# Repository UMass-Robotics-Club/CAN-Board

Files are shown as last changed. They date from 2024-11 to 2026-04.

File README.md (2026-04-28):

# CAN Board
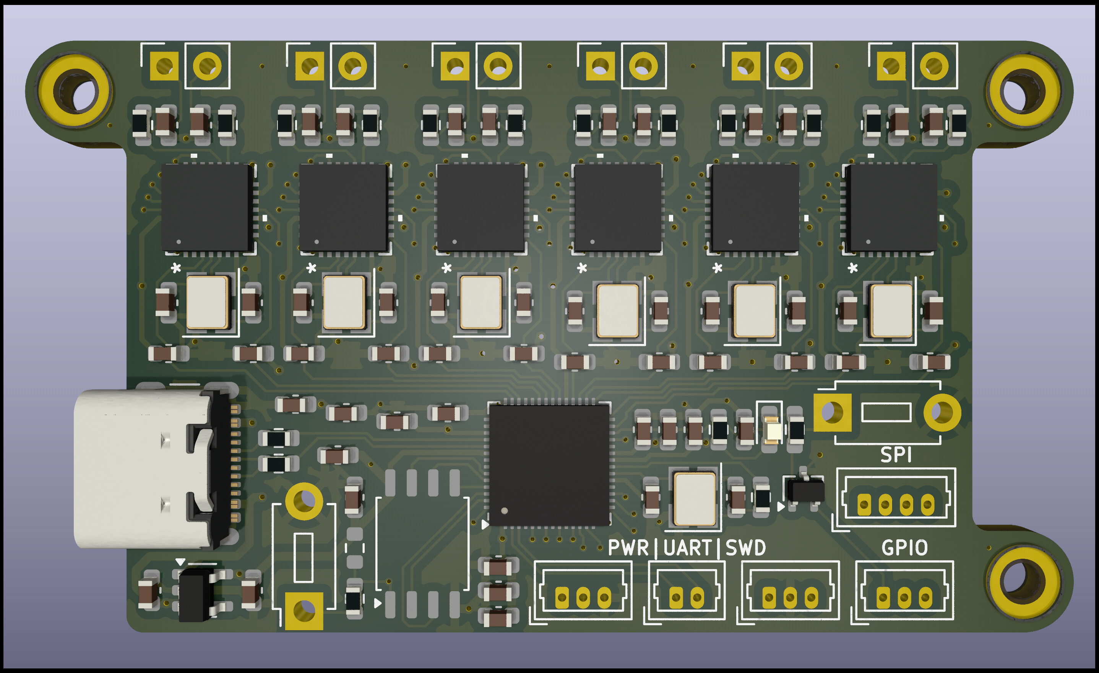
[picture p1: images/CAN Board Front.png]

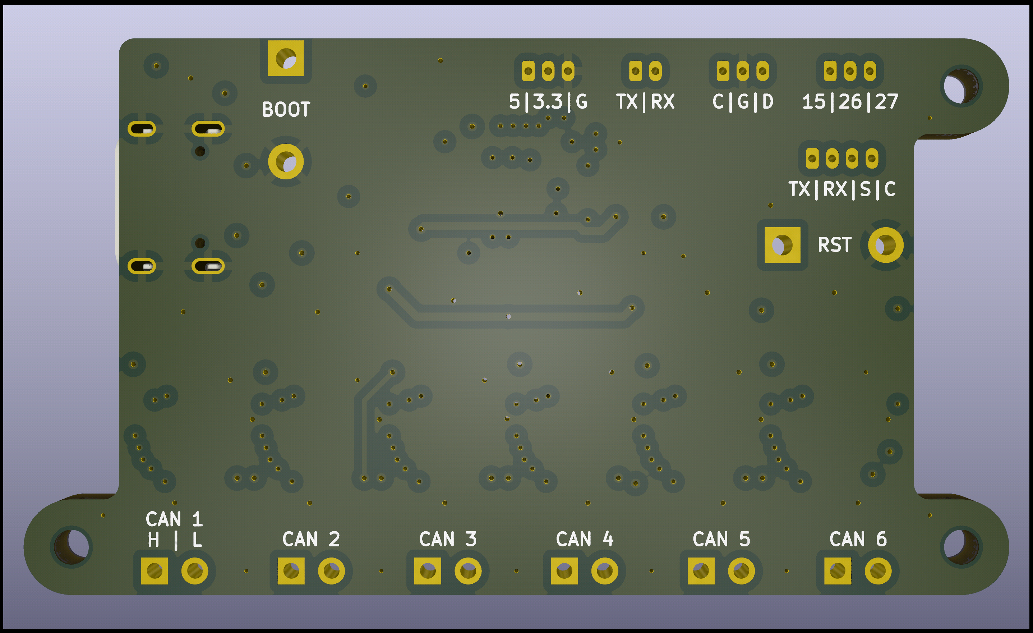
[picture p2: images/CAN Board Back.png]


Features:
* 6 CAN lines
* [RP2040](https://datasheets.raspberrypi.com/rp2040/rp2040-datasheet.pdf) microcontroller
* 16MB flash
* Many Interfaces
    * USB-C
    * UART
    * SPI
    * GPIO
* SWD debugging

This board has 6 independent CAN lines driven by 6 [MCP251863T-E/9PX](https://ww1.microchip.com/downloads/aemDocuments/documents/APID/ProductDocuments/DataSheets/MCP251863-External-CAN-FD-Controller-with-Integrated-Transceiver-DS200066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) CAN controllers. Each CAN controller is interfaced with the central microcontroller through an internal SPI bus along with 2 interrupt pins for general purpose and RX interrupts. There is also a STBY pin for the CAN transceiver that is connected to the XSTBY pin on the CAN controller.

## RP2040 Pinout
| GPIO | Function |
|---|---|
| 0 | UART TX | 
| 1 | UART RX |
| 2 | SPI0 SCK |
| 3 | SPI0 TX |
| 4 | SPI0 RX |
| 5 | SPI0 CS 1 |
| 6 | SPI0 CS 2 |
| 7 | SPI0 CS 3 |
| 8 | SPI0 CS 4 |
| 9 | SPI0 CS 5 |
| 10 | SPI0 CS 6 |
| 11 | SPI1 TX |
| 12 | SPI1 RX |
| 13 | SPI1 CS |
| 14 | SPI1 SCK |
| 15 | GPIO pin 1 |
| 16 | CAN6 RX INT |
| 17 | CAN6 INT |
| 18 | CAN5 RX INT |
| 19 | CAN5 INT |
| 20 | CAN4 RX INT |
| 21 | CAN4 INT |
| 22 | CAN3 RX INT |
| 23 | CAN3 INT |
| 24 | CAN2 RX INT |
| 25 | CAN2 INT |
| 26 | GPIO pin 2 |
| 27 | GPIO pin 3 |
| 28 | CAN1 RX INT |
| 29 | CAN1 INT |

Notes:
* `SPI0` is the internal SPI bus which connects to the CAN controllers with `SPI0 CS X` being the chip select for CAN controller X.
* `SPI1` is the SPI bus exposed over the SPI connector.
* `GPIO 15 (GPIO pin 1)` is attached to a mosfet and LED as an indicator and therefore should have pull down enabled if being used as an input.
* `GPIO 26 & 27 (GPIO pin 26 & 27)` can be used an analog inputs.
* `CANX INT` is a general purpose interrupt pin for CAN controller X that will trigger when any interrupt in the CAN controller is triggered. This pin is inverted (active LOW).
* `CANX RX INT` is configurable to trigger when CAN controller X's RX interrupt is triggered. As an interrupt, this pin is inverted (active LOW).

## Project Structure
* `CAD`: The kiCAD project (PCB/schematics)
    * `Components`: Imported components each in their own folder
* `code`: Firmware for the microcontroller in a pretty standard C project structure
    * `include`: Header files
    * `src`: C/C++ files
* `images`: All the images

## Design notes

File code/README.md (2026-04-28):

# Firmware for CAN Controller
This firmware is made for the RP2040 using the [picoSDK](https://github.com/raspberrypi/pico-sdk) along with the [CAN SDK](https://github.com/kentindell/canis-can-sdk) by [CANIS labs](https://canislabs.com/canpico/) to interface with the CAN controllers.

## Configuration
### Logging
By default, the firmware will output all log messages over USB. You can change what level of messages get logged by changing what macros are defined right above `#include "logging.h"` in [main.c](./src/main.c). You can also select what these messages are sent over (USB/external UART) by modifying the bottom of [CMakeLists.txt](./CMakeLists.txt).

### SPI and CAN
You can change both the SPI BAUD rate and the CAN bitrate at the top of [main.c](./src/main.c) under the user params section. The predefined CAN bit rates are in [canapi.h](./include/canapi.h) as follows:
```c
CAN_BITRATE_500K_75 = 0,    // 500kbit/sec 75% sample (default)    
CAN_BITRATE_250K_75,        // 250kbit/sec 75% sample point 
CAN_BITRATE_125K_75,        // 125kbit/sec 75% sample point
CAN_BITRATE_1M_75,          // 1Mbit/sec 75% sample point
CAN_BITRATE_500K_50,        // 500kbit/sec 50% sample (default)
CAN_BITRATE_250K_50,        // 250kbit/sec 50% sample point 
CAN_BITRATE_125K_50,        // 125kbit/sec 50% sample point
CAN_BITRATE_1M_50,          // 1Mbit/sec 50% sample point
CAN_BITRATE_2M_50,          // 2Mbit/sec 50% sample point NON STANDARD
CAN_BITRATE_4M_90,          // 4Mbit/sec 50% sample point NON STANDARD
CAN_BITRATE_2_5M_75 ,       // 2.5Mbit/sec 75% sample point NON STANDARD
CAN_BITRATE_2M_80,          // 2Mbit/sec 80% sample point NON STANDARD
CAN_BITRATE_500K_875,       // 500kbit/sec 87.5% sample
CAN_BITRATE_250K_875,       // 250kbit/sec 87.5% sample point (J1939, CANOpen) 
CAN_BITRATE_125K_875,       // 125kbit/sec 87.5% sample point
CAN_BITRATE_1M_875,         // 1Mbit/sec 85.5% sample point
```

## Build Instructions
1. Make a build folder inside `code`
```
mkdir build
cd build
```
2. Create the make files thorough cmake
```
cmake ..
```
3. Build the firmware using make
```
make
```
4. The output files should be inside the `build` folder

## Upload
```
sudo openocd -f interface/cmsis-dap.cfg -f target/rp2040.cfg -c "adapter speed 5000" -c "program can_board.elf verify reset exit"
```

## debug
```
gdb ./build/can_board.elf -ex 'set arch arm' -ex 'target extended-remote :3333'
```

# Better Communication Protocol

## Overall Architecture
The protocol is half duplex (even if the underlying transport is full duplex) and is based on a host-peripheral command architecture. The host will send a command along with any needed data and the peripheral will respond with a status code along with any data to return. The host MUST wait to the peripheral to respond before sending another command. If the peripheral does not receive a packet in time then it will send a timeout packet back. All data and commands will be wrapped in a general packet structure defined below. 

### General Command Structure
Host -> Peripheral:
- Frame start (1 byte): 0xAA
- Command (1 byte): The command that the controller should execute
- Data size (2 bytes): The size of the data included
- Data (n bytes): The data for the command (command specific)
- Frame end (1 byte): 0x55

Peripheral -> Host:
- Frame start (1 byte): 0xAA
- Response Code (1 byte): Status of the command
- Data size (2 bytes): The size of the data included
- Data (n bytes): The data for the command (command specific)
- Frame end (1 byte): 0x55

### Specific Command Structure
#### Send CAN Frame Command
Host -> Peripheral Data:
- Controller ID (1 byte): The ID of the controller to send the frame on
- Frame Options (1 byte): The options for the frame (e.g. extended ID, remote frame, etc.)
- Data Length Code (1 byte): The length of the data in bytes (0-8)
- Arbitration ID (2-4 bytes): The arbitration ID of the frame
- Frame Data (0-8 bytes): The data to be sent in the frame

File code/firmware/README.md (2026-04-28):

# Firmware — CAN Controller Board

## Overview

This folder contains the RP2040 firmware for the CAN controller board. It uses the Raspberry Pi Pico SDK and the MCP25xxFD CAN driver.

- **Microcontroller:** Raspberry Pi RP2040 (Pico)
- **CAN Controller:** MCP25xxFD (via SPI)
- **Number of CAN controllers:** 6 (configurable)
- **Communication:** USB CDC (default) or external SPI
- **Protocol:** Simple framed packet protocol (half-duplex, command-response)

## Contents

| Item | Purpose |
|---|---|
| [src/](src/) | Application sources: [main.c](src/main.c), [can.c](src/can.c) |
| [include/](include/) | Headers: [can.h](include/can.h), [pins.h](include/pins.h), [logging.h](include/logging.h) |
| [lib/mcp25xxfd/](lib/mcp25xxfd/) | Third-party MCP25xxFD CAN driver and RP2040 bindings |
| [CMakeLists.txt](CMakeLists.txt) | CMake build configuration for Pico SDK |

## Quick Start (Command-line Build)

From the `code` directory:

```bash
mkdir build
cd build
cmake ..
make
```

Build outputs: `can_board.elf`, `can_board.uf2` in `build/` directory.

## Building & Uploading with VS Code + Pico Extension

### Installation

1. **Install the official Raspberry Pi Pico extension**
   - Open VS Code Extensions (`Ctrl+Shift+X`)
   - Search for `Raspberry Pi Pico` (Publisher: Raspberry Pi)
   - Click **Install** on the official [Raspberry Pi Pico extension](https://marketplace.visualstudio.com/items?itemName=raspberry-pi.raspberry-pi-pico)
   - The extension will automatically download and configure the toolchain, SDK, and build tools (Ninja, CMake, arm-none-eabi-gcc)
   - **No manual toolchain installation required** — the extension handles it all

2. **Platform-specific notes**
   - **Windows / Raspberry Pi OS**: No additional prerequisites
   - **macOS**: Run `xcode-select --install` to install Xcode Command Line Tools
   - **Linux**: Ensure Python 3.10+, Git 2.28+, and Tar are installed and on your `PATH`

### Project Setup

1. **Open the folder in VS Code**
   - Open the project folder in VS Code (single folder workspace only)
   - The Pico extension will automatically detect the `CMakeLists.txt`

2. **Extension auto-configuration**
   - The extension automatically configures CMake on project load
   - You'll see the Pico extension status in the status bar at the bottom
   - If prompted, select **"Pico"** as the CMake kit

### Build Workflow

1. **Build** — Use any of the following:
   - Click the **Compile** button in the Pico extension status bar (bottom right)
   - Run `Ctrl+Shift+P` → Search `Raspberry Pi Pico: Compile Project`
   - Build output appears in the terminal; artifacts in `build/` folder (`can_board.elf`, `can_board.uf2`, etc.)

2. **Flash/Upload** — After building successfully:
   - **Option A (UF2 mass-storage, easiest):**
     - Put Pico into BOOTSEL mode: Hold BOOTSEL button while plugging USB into computer
     - Mounted drive will appear (RPI-RP2)
     - Copy `build/can_board.uf2` to the drive
     - Pico will auto-reboot and run the firmware
   
   - **Option B (Picotool, via extension):**
     - Connect Pico via USB with SWD/JTAG debugger (optional)
     - Run `Ctrl+Shift+P` → Search `Raspberry Pi Pico: Upload Project` (if available)
     - Extension uses `picotool` to flash via USB

3. **Debug** (optional, requires hardware debugger):
   - Connect CMSIS-DAP, ST-Link, or other SWD debugger to Pico
   - Run `Ctrl+Shift+P` → Search `Raspberry Pi Pico: Debug Project`
   - Extension automatically configures OpenOCD and GDB
   - Set breakpoints and step through code in the debugger

### Troubleshooting Extension Issues

- **CMake configuration fails**: Clear extension settings (`Ctrl+Shift+P` → `Preferences: Open Settings (UI)` → search `raspberry-pi-pico` → reset to defaults) then reload VS Code
- **Tools not downloading**: Check GitHub API rate limits; create a GitHub personal access token (with `public_repo` scope) and add to `raspberry-pi-pico.githubToken` in settings
- **Build fails**: Ensure `pico_sdk_import.cmake` is in the `firmware/` directory (it is, by default)

## Configuration

All configuration options are located in the files below. Edit them before building.

### Logging — [include/logging.h](include/logging.h)

Enable/disable log levels by defining or commenting out:

```c
#define ENABLE_TEST      // Development/testing (interferes with protocol in IRQ handler!)
#define ENABLE_DEBUG     // Debug-level messages
#define ENABLE_INFO      // Informational messages
#define ENABLE_WARNING   // Warning messages
#define ENABLE_ERROR     // Error messages
```

### Pins & Interfaces — [include/pins.h](include/pins.h)

| Parameter | Default | Purpose |
|---|---|---|
| `CAN_SPI` | `spi0` | Primary SPI bus for all 6 CAN controllers |
| `CAN_SPI_SCK` | 2 | SPI clock pin |
| `CAN_SPI_TX` | 3 | SPI TX (MOSI) pin |
| `CAN_SPI_RX` | 4 | SPI RX (MISO) pin |
| `can_spi_cs_pins[6]` | 5,6,7,8,9,10 | Chip select pins for 6 controllers |
| `can_int_pins[6]` | 29,25,23,21,19,17 | Interrupt pins for 6 controllers |
| `EXT_SPI` | `spi1` | External SPI (when `PKT_OVER_STDIO` is undefined) |
| `EXT_SPI_TX` | 11 | External SPI TX pin |
| `EXT_SPI_RX` | 12 | External SPI RX pin |
| `EXT_SPI_SCK` | 14 | External SPI clock pin |
| `EXT_SPI_CS` | 13 | External SPI chip select pin |
| `EXT_GPIO_15` | 15 | Activity LED GPIO (toggled during command processing) |

### User Parameters — [src/main.c](src/main.c)

Located in the "User params" section at the top of the file:

```c
#define EXT_SPI_BAUD 1000000        // External SPI baud rate (1 MHz default)
#define CAN_BITRATE CAN_BITRATE_1M_50   // CAN bitrate (see list below)
#define PKT_OVER_STDIO              // Use USB CDC for packets (comment to use EXT_SPI)
```

#### CAN Bitrate Profiles

All profiles are defined in [lib/mcp25xxfd/canapi.h](lib/mcp25xxfd/canapi.h). Use one as the value for `CAN_BITRATE`:

**Standard bitrates (75% sample point)**
- `CAN_BITRATE_500K_75` — 500 kbit/sec (default)
- `CAN_BITRATE_250K_75` — 250 kbit/sec
- `CAN_BITRATE_125K_75` — 125 kbit/sec
- `CAN_BITRATE_1M_75` — 1 Mbit/sec

**Standard bitrates (50% sample point)**
- `CAN_BITRATE_500K_50` — 500 kbit/sec
- `CAN_BITRATE_250K_50` — 250 kbit/sec
- `CAN_BITRATE_125K_50` — 125 kbit/sec
- `CAN_BITRATE_1M_50` — 1 Mbit/sec

**High-speed bitrates (50% sample point, non-standard)**
- `CAN_BITRATE_2M_50` — 2 Mbit/sec
- `CAN_BITRATE_4M_90` — 4 Mbit/sec (90% sample)

**Specialized bitrates (75%-87.5% sample points)**
- `CAN_BITRATE_2_5M_75` — 2.5 Mbit/sec (75% sample)
- `CAN_BITRATE_2M_80` — 2 Mbit/sec (80% sample)
- `CAN_BITRATE_500K_875` — 500 kbit/sec (87.5% sample)
- `CAN_BITRATE_250K_875` — 250 kbit/sec (87.5% sample, J1939/CANopen)
- `CAN_BITRATE_125K_875` — 125 kbit/sec (87.5% sample)
- `CAN_BITRATE_1M_875` — 1 Mbit/sec (85.5% sample)

**Custom bitrate**
- `CAN_BITRATE_CUSTOM` — Use a custom profile (manually set `brp`, `tseg1`, `tseg2`, `sjw` in `can_bitrate_t`)

### Controller Limits — [include/can.h](include/can.h)

```c
#define NUM_CAN_CONTROLLERS 6           // Number of MCP25xxFD controllers (fixed to 6)
#define CAN_SETUP_MAX_RETRIES 5         // Setup retry count (if transceiver slow to power)
#define CAN_TRANSMIT_MAX_TRYS 1         // Transmit retry count
```

## Code Structure

### [src/main.c](src/main.c)

**Entry point and packet loop.**

- **`main()`** — Initializes stdio, waits for USB CDC connection, initializes external SPI, calls `setup_can_controllers()`, enters main packet loop.
- **`loop()`** — Reads framed packets from transport (stdio or SPI), dispatches commands, sends responses.
- **Command handlers** — `handle_send_frame_cmd()`, `handle_recv_rx_events_cmd()`, `handle_recv_tx_events_cmd()`.

**Defines:**
- `host_command_t` — Command enum (SEND_FRAME, RECV_RX_EVENTS, RECV_TX_EVENTS, RECV_CAN_INFO)
- `command_resp_t` — Response codes (OK, BAD_PKT, CMD_UNKNOWN, CMD_MALFORMED, TIMEOUT, FAILED, NO_RESOURCES)
- `frame_options_t` — Frame flags (EXTENDED, REMOTE, USE_FIFO, USE_UREF)

### [src/can.c](src/can.c)

**CAN controller management and IRQ handling.**

- **`setup_can_controllers()`** — Initializes all 6 CAN controllers with given bitrate.
- **`send_can_frame()`** — Queue a CAN frame for transmission (with retries).
- **`get_can_rx_events()`** — Retrieve pending RX events for a controller.
- **`get_can_tx_events()`** — Retrieve pending TX events for a controller.
- **`can_irq_handler()`** — Shared IRQ handler (TIME_CRITICAL) that services all controllers.

### [include/can.h](include/can.h)

**Public constants and function declarations:**
- `NUM_CAN_CONTROLLERS`
- `can_controllers[]` — Array of `can_controller_t` instances
- Function prototypes for setup, send, and event retrieval

### [include/pins.h](include/pins.h)

**Board pin definitions:**
- SPI pins for CAN controllers
- External UART/SPI pins
- CS and interrupt pin arrays
- GPIO pins for activity indication

### [include/logging.h](include/logging.h)

**Logging macros:**
- `test()`, `debug()`, `info()`, `warning()`, `error()`
- Enable/disable via preprocessor defines
- Output via printf (configured in CMake to use stdio USB or UART)

### [lib/mcp25xxfd/](lib/mcp25xxfd/)

**Third-party CAN driver:**
- [lib/mcp25xxfd/canapi.h](lib/mcp25xxfd/canapi.h) — CAN API, bitrate profiles, data structures
- [lib/mcp25xxfd/mcp25xxfd.c](lib/mcp25xxfd/mcp25xxfd.c) — Main driver implementation
- [lib/mcp25xxfd/rp2/mcp25xxfd-rp2.h](lib/mcp25xxfd/rp2/mcp25xxfd-rp2.h) — RP2040-specific bindings

See [lib/mcp25xxfd/canapi.h](lib/mcp25xxfd/canapi.h) for `can_frame_t`, `can_rx_event_t`, `can_tx_event_t`, and other data structures.

## Host ↔ Peripheral Protocol

### Overview

The firmware implements a **half-duplex, framed packet protocol** over either USB CDC (STDIO) or external SPI. The host sends a command, the peripheral processes it, and responds with a status code and optional data.

### Packet Frame Format (both directions)

```
[0xAA] [Command/Response] [Data Size (2 bytes LE)] [Data (n bytes)] [0x55]
```

| Field | Size | Value |
|---|---|---|
| Frame start | 1 byte | `0xAA` |
| Command (host) / Response (peripheral) | 1 byte | See tables below |
| Data size | 2 bytes | Little-endian, 0–65535 |
| Data | n bytes | Command-specific payload |
| Frame end | 1 byte | `0x55` |

### Host → Peripheral Commands

From [src/main.c](src/main.c) `host_command_t`:

| Command | Byte | Payload | Purpose |
|---|---|---|---|
| `SEND_FRAME` | 0 | CAN frame + options | Send a CAN frame on specified controller |
| `RECV_RX_EVENTS` | 1 | Controller ID (1 byte) | Request pending RX events |
| `RECV_TX_EVENTS` | 2 | Controller ID (1 byte) | Request pending TX events |
| `RECV_CAN_INFO` | 3 | (reserved) | Reserved for future use |

### Peripheral → Host Responses

From [src/main.c](src/main.c) `command_resp_t`:

| Response | Value | Meaning |
|---|---|---|
| `CMD_RESPONSE_OK` | 0 | Success |
| `CMD_RESPONSE_BAD_PKT` | 1 | Frame start/end invalid |
| `CMD_RESPONSE_CMD_UNKNOWN` | 2 | Unknown command code |
| `CMD_RESPONSE_CMD_MALFORMED` | 3 | Payload size mismatch or invalid parameters |
| `CMD_RESPONSE_TIMEOUT` | 4 | Timeout waiting for input |
| `CMD_RESPONSE_FAILED` | 5 | Command execution failed (e.g., TX queue full) |
| `CMD_RESPONSE_NO_RESOURCES` | 6 | Memory allocation failed |

### SEND_FRAME Command Details

**Payload structure:**

```
[Controller ID] [Frame Options] [DLC] [Arbitration ID] [User Ref?] [Data]
```

| Field | Size | Notes |
|---|---|---|
| Controller ID | 1 byte | 0–5 (for 6 controllers) |
| Frame Options | 1 byte | Bit flags (see below) |
| DLC | 1 byte | Data length 0–8 |
| Arbitration ID | 2 or 4 bytes | 2 bytes if standard (11-bit), 4 bytes if extended (29-bit) |
| User Reference | 4 bytes | *Optional*, only if `FRAME_OPTION_USE_UREF` set |
| Frame Data | 0–8 bytes | Omitted if remote frame; length = DLC |

**Frame Options Flags:**

| Flag | Bit | Meaning |
|---|-----|---|
| `FRAME_OPTION_EXTENDED` | 0 (1<<0) | 29-bit arbitration ID (else 11-bit) |
| `FRAME_OPTION_REMOTE` | 1 (1<<1) | Remote frame (no data payload) |
| `FRAME_OPTION_USE_FIFO` | 2 (1<<2) | Use TX FIFO (else priority queue) |
| `FRAME_OPTION_USE_UREF` | 3 (1<<3) | Include 4-byte user reference |

**Example: Send 8-byte frame on controller 0, standard ID 0x123**

```
Frame start:     0xAA
Command:         0x00 (SEND_FRAME)
Data size:       0x0C, 0x00 (12 bytes)
Controller:      0x00
Options:         0x00 (standard, not remote, priority queue, no uref)
DLC:             0x08 (8 bytes)
Arbitration ID:  0x23, 0x01 (0x0123 LE)
Frame data:      0xAA, 0xBB, 0xCC, 0xDD, 0xEE, 0xFF, 0x00, 0x11
Frame end:       0x55
```

### RX/TX Events

- **`RECV_RX_EVENTS`** — Returns a packed buffer of receive events. Each event is `NUM_RX_EVENT_BYTES` bytes (19 bytes typically). Include the CAN frame, timestamp, and event type.
- **`RECV_TX_EVENTS`** — Returns a packed buffer of transmit events. Each event is `NUM_TX_EVENT_BYTES` bytes (9 bytes typically). Include user reference and timestamp.

See [lib/mcp25xxfd/canapi.h](lib/mcp25xxfd/canapi.h) for event structure definitions.

## Implementation Notes

### Key Points

- **Half-duplex protocol** — Host must wait for peripheral response before sending the next command.
- **Transport selection** — `PKT_OVER_STDIO` in [src/main.c](src/main.c) switches between USB CDC and external SPI.
- **Shared SPI bus** — All 6 CAN controllers share one SPI bus; IRQ handling adapted in [src/can.c](src/can.c).
- **Packet validation** — Strict size checking; mismatches return `CMD_RESPONSE_CMD_MALFORMED`.
- **Retry logic** — Controller setup retries up to `CAN_SETUP_MAX_RETRIES` times; useful if 3.3V present but 5V absent (affects transceiver power).

### Logging Output

- **Default:** USB CDC (`stdio_usb`)
- **Also available:** UART (`stdio_uart`)
- **Configure:** [CMakeLists.txt](CMakeLists.txt) — `pico_enable_stdio_usb()` and `pico_enable_stdio_uart()`

### Custom Bitrate

To use a custom bitrate, set `CAN_BITRATE` to `CAN_BITRATE_CUSTOM` and populate the `can_bitrate_t` struct in [src/main.c](src/main.c):

```c
can_bitrate_t bitrate = {
    .profile = CAN_BITRATE_CUSTOM,
    .brp = ...,       // Baud rate prescaler
    .tseg1 = ...,     // TSEG1 - 1
    .tseg2 = ...,     // TSEG2 - 1
    .sjw = ...        // SJW - 1
};
```

## Important Files Summary

| File | Purpose |
|---|---|
| [src/main.c](src/main.c) | Main loop, packet parsing, command handlers |
| [src/can.c](src/can.c) | CAN setup, IRQ handler, event retrieval |
| [include/pins.h](include/pins.h) | Pin definitions |
| [include/logging.h](include/logging.h) | Logging configuration |
| [include/can.h](include/can.h) | Public CAN constants |
| [lib/mcp25xxfd/canapi.h](lib/mcp25xxfd/canapi.h) | CAN API, bitrates, structures |
| [CMakeLists.txt](CMakeLists.txt) | Build configuration |

## Troubleshooting

**CAN controller fails to initialize**
- Check that 5V power is present on the transceiver (separate from 3.3V).
- Verify SPI pins and CS/IRQ pin assignments in [include/pins.h](include/pins.h).

**No USB CDC output**
- Ensure `pico_enable_stdio_usb()` is active in [CMakeLists.txt](CMakeLists.txt).
- Try toggling `PKT_OVER_STDIO` in [src/main.c](src/main.c) to use external SPI instead.

**Packets not received**
- Check transport (USB CDC vs. external SPI) is correctly selected and connected.
- Verify frame start (`0xAA`) and end (`0x55`) bytes are correct.
- Confirm controller ID is in range 0–5.

## Next Steps

- Add a Python host example that sends `SEND_FRAME` packets over USB CDC.
- Add `.vscode/launch.json` snippet for OpenOCD + GDB debugging (hardware debugger required).
- Add unit tests for packet parsing and frame layout validation.

---

Generated from firmware code analysis. Last updated: April 2026.

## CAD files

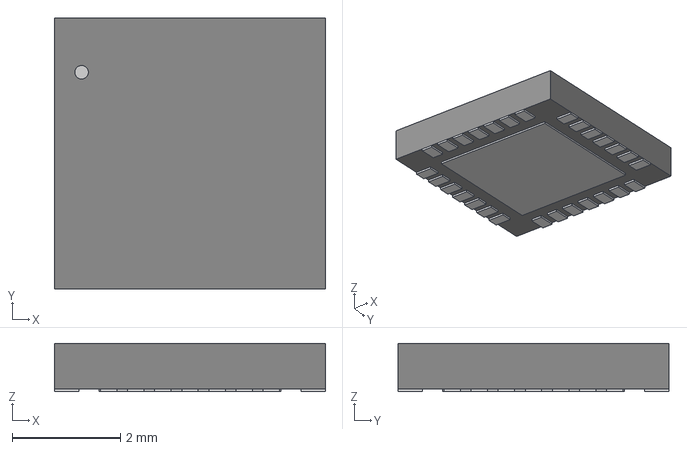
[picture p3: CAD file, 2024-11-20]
CAD/Components/MCP251863T_E_9PX/VQFN28_9PX_3p25X3p25EPAD_MCH.step
5.00 x 5.00 x 0.892 mm

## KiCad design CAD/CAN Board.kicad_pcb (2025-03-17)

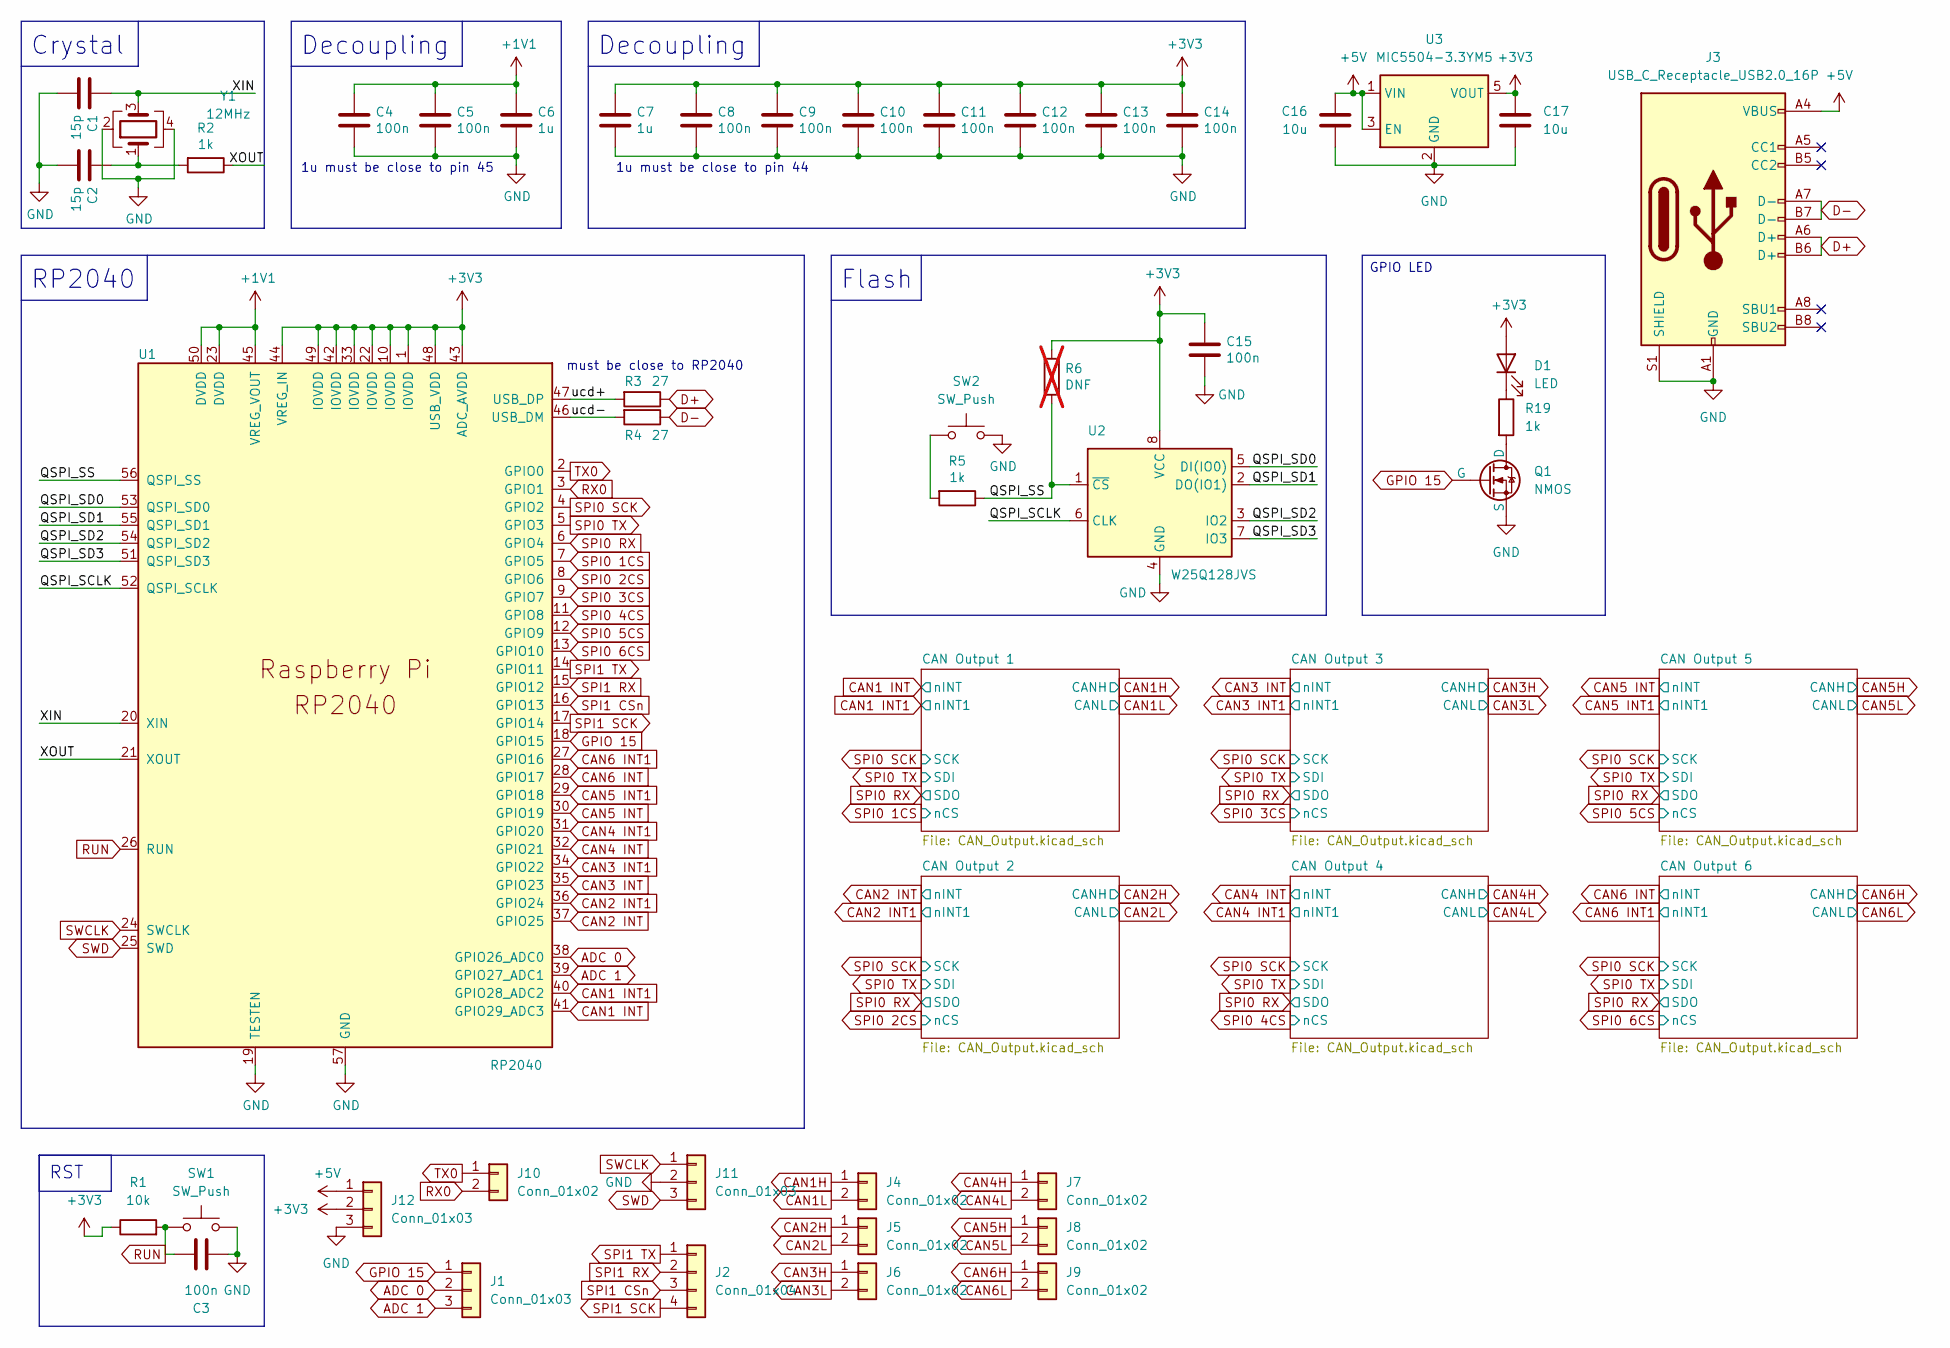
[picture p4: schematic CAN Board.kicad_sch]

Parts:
C1, C2: 15p; C_0603_1608Metric
C3, C4, C5, C8, C9, C10, C11, C12, C13, C14, C15: 100n; C_0603_1608Metric
C6, C7: 1u; C_0603_1608Metric
C16, C17: 10u; C_0603_1608Metric
D1: LED; LED_0603_1608Metric_Pad1.05x0.95mm_HandSolder
J1, J11, J12: Conn_01x03; Molex_PicoBlade_53047-0310_1x03_P1.25mm_Vertical
J2: Conn_01x04; Molex_PicoBlade_53047-0410_1x04_P1.25mm_Vertical
J3: USB_C_Receptacle_USB2.0_16P; USB_C_Receptacle_GCT_USB4105-xx-A_16P_TopMnt_Horizontal
J4, J5, J6, J7, J8, J9: Conn_01x02; PinSocket_1x02_P2.54mm_Vertical
J10: Conn_01x02; Molex_PicoBlade_53047-0210_1x02_P1.25mm_Vertical
Q1: NMOS; SOT-323_SC-70
R1: 10k; R_0603_1608Metric
R2, R5, R19: 1k; R_0603_1608Metric
R3, R4: 27; R_0603_1608Metric
R6: DNF; R_0603_1608Metric; not fitted
SW1, SW2: SW_Push; SW_PUSH_1P1T_6x3.5mm_H5.0_APEM_MJTP1250
U1: RP2040; QFN-56-1EP_7x7mm_P0.4mm_EP3.2x3.2mm
U2: W25Q128JVS; SOIC-8_5.23x5.23mm_P1.27mm
U3: MIC5504-3.3YM5; SOT-23-5
Y1: 12MHz; Crystal_SMD_3225-4Pin_3.2x2.5mm

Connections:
+1V1: C4.1, C5.1, C6.1, U1.23 (DVDD), U1.45 (VREG_VOUT), U1.50 (DVDD)
+3V3: C7.1, C8.1, C9.1, C10.1, C11.1, C12.1, C13.1, C14.1, C15.1, C17.1, D1.2 (A), J12.2, R1.1, R6.1, U1.1 (IOVDD), U1.10 (IOVDD), U1.22 (IOVDD), U1.33 (IOVDD), U1.42 (IOVDD), U1.43 (ADC_AVDD), U1.44 (VREG_IN), U1.48 (USB_VDD), U1.49 (IOVDD), U2.8 (VCC), U3.5 (VOUT); also elsewhere on the board
+5V: C16.1, J3.A4 (VBUS), J3.A9 (VBUS), J3.B4 (VBUS), J3.B9 (VBUS), J12.1, U3.1 (VIN), U3.3 (EN); also elsewhere on the board
/QSPI_SCLK: U1.52 (QSPI_SCLK), U2.6 (CLK)
/QSPI_SD0: U1.53 (QSPI_SD0), U2.5 (DI(IO0))
/QSPI_SD1: U1.55 (QSPI_SD1), U2.2 (DO(IO1))
/QSPI_SD2: U1.54 (QSPI_SD2), U2.3 (IO2)
/QSPI_SD3: U1.51 (QSPI_SD3), U2.7 (IO3)
/QSPI_SS: R5.1, R6.2, U1.56 (QSPI_SS), U2.1 (~CS)
/XIN: C1.1, U1.20 (XIN), Y1.3
/XOUT: R2.1, U1.21 (XOUT)
/ucd+: R3.2, U1.47 (USB_DP)
/ucd-: R4.2, U1.46 (USB_DM)
ADC 0: J1.2, U1.38 (GPIO26_ADC0)
ADC 1: J1.3, U1.39 (GPIO27_ADC1)
CAN1 INT: U1.41 (GPIO29_ADC3); also elsewhere on the board
CAN1 INT1: U1.40 (GPIO28_ADC2); also elsewhere on the board
CAN1H: J4.1; also elsewhere on the board
CAN1L: J4.2; also elsewhere on the board
CAN2 INT: U1.37 (GPIO25); also elsewhere on the board
CAN2 INT1: U1.36 (GPIO24); also elsewhere on the board
CAN2H: J5.1; also elsewhere on the board
CAN2L: J5.2; also elsewhere on the board
CAN3 INT: U1.35 (GPIO23); also elsewhere on the board
CAN3 INT1: U1.34 (GPIO22); also elsewhere on the board
CAN3H: J6.1; also elsewhere on the board
CAN3L: J6.2; also elsewhere on the board
CAN4 INT: U1.32 (GPIO21); also elsewhere on the board
CAN4 INT1: U1.31 (GPIO20); also elsewhere on the board
CAN4H: J7.1; also elsewhere on the board
CAN4L: J7.2; also elsewhere on the board
CAN5 INT: U1.30 (GPIO19); also elsewhere on the board
CAN5 INT1: U1.29 (GPIO18); also elsewhere on the board
CAN5H: J8.1; also elsewhere on the board
CAN5L: J8.2; also elsewhere on the board
CAN6 INT: U1.28 (GPIO17); also elsewhere on the board
CAN6 INT1: U1.27 (GPIO16); also elsewhere on the board
CAN6H: J9.1; also elsewhere on the board
CAN6L: J9.2; also elsewhere on the board
D+: J3.A6 (D+), J3.B6 (D+), R3.1
D-: J3.A7 (D-), J3.B7 (D-), R4.1
GND: C1.2, C2.2, C3.2, C4.2, C5.2, C6.2, C7.2, C8.2, C9.2, C10.2, C11.2, C12.2, C13.2, C14.2, C15.2, C16.2, C17.2, J3.A1 (GND), J3.A12 (GND), J3.B1 (GND), J3.B12 (GND), J3.S1 (SHIELD), J11.2, J12.3, Q1.3 (S), SW1.2, SW2.2, U1.19 (TESTEN), U1.57 (GND), U2.4 (GND), U3.2 (GND), Y1.2, Y1.4; also elsewhere on the board
GPIO 15: J1.1, Q1.2 (G), U1.18 (GPIO15)
unnamed: C2.1, R2.2, Y1.1
unnamed: D1.1 (K), R19.1
unnamed: Q1.1 (D), R19.2
unnamed: R5.2, SW2.1
RUN: C3.1, R1.2, SW1.1, U1.26 (RUN)
RX0: J10.2, U1.3 (GPIO1)
SPI0 1CS: U1.7 (GPIO5); also elsewhere on the board
SPI0 2CS: U1.8 (GPIO6); also elsewhere on the board
SPI0 3CS: U1.9 (GPIO7); also elsewhere on the board
SPI0 4CS: U1.11 (GPIO8); also elsewhere on the board
SPI0 5CS: U1.12 (GPIO9); also elsewhere on the board
SPI0 6CS: U1.13 (GPIO10); also elsewhere on the board
SPI0 RX: U1.6 (GPIO4); also elsewhere on the board
SPI0 SCK: U1.4 (GPIO2); also elsewhere on the board
SPI0 TX: U1.5 (GPIO3); also elsewhere on the board
SPI1 CSn: J2.3, U1.16 (GPIO13)
SPI1 RX: J2.2, U1.15 (GPIO12)
SPI1 SCK: J2.4, U1.17 (GPIO14)
SPI1 TX: J2.1, U1.14 (GPIO11)
SWCLK: J11.1, U1.24 (SWCLK)
SWD: J11.3, U1.25 (SWD)
TX0: J10.1, U1.2 (GPIO0)

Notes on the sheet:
Crystal
RP2040
Decoupling
Flash
must be close to RP2040
1u must be close to pin 45
1u must be close to pin 44
GPIO LED
RST

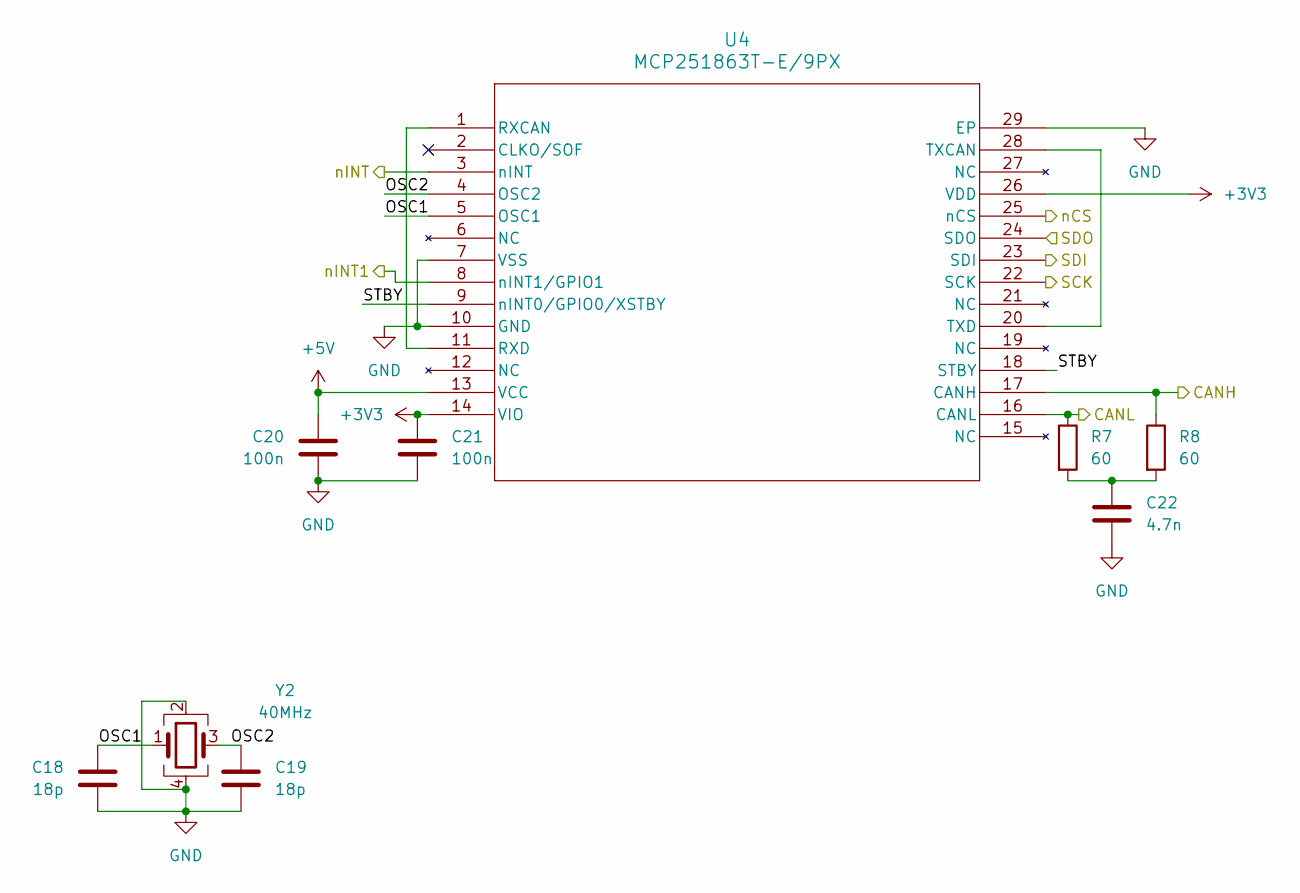
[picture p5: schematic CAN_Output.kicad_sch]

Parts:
C18, C19: 18p; C_0603_1608Metric
C20, C21: 100n; C_0603_1608Metric
C22: 4.7n; C_0603_1608Metric
R7, R8: 60; R_0603_1608Metric
U4: MCP251863T-E/9PX; VQFN28_9PX_3p25X3p25EPAD_MCH
Y2: 40MHz; Crystal_SMD_3225-4Pin_3.2x2.5mm

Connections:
+3V3: C21.1, U4.14 (VIO), U4.26 (VDD); also elsewhere on the board
+5V: C20.1, U4.13 (VCC); also elsewhere on the board
/CAN Output 1/OSC1: C18.1, U4.5 (OSC1), Y2.1
/CAN Output 1/OSC2: C19.1, U4.4 (OSC2), Y2.3
/CAN Output 1/STBY: U4.9 (nINT0/GPIO0/XSTBY), U4.18 (STBY)
CAN1 INT: U4.3 (nINT); also elsewhere on the board
CAN1 INT1: U4.8 (nINT1/GPIO1); also elsewhere on the board
CAN1H: R8.1, U4.17 (CANH); also elsewhere on the board
CAN1L: R7.1, U4.16 (CANL); also elsewhere on the board
GND: C18.2, C19.2, C20.2, C21.2, C22.2, U4.7 (VSS), U4.10 (GND), U4.29 (EP), Y2.2, Y2.4; also elsewhere on the board
unnamed: C22.1, R7.2, R8.2
unnamed: U4.1 (RXCAN), U4.11 (RXD)
unnamed: U4.20 (TXD), U4.28 (TXCAN)
SPI0 1CS: U4.25 (nCS); also elsewhere on the board
SPI0 RX: U4.24 (SDO); also elsewhere on the board
SPI0 SCK: U4.22 (SCK); also elsewhere on the board
SPI0 TX: U4.23 (SDI); also elsewhere on the board

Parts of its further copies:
C25, C26, C32, C33, C39, C40, C46, C47, C53, C54: 18p; C_0603_1608Metric
C27, C28, C34, C35, C41, C42, C48, C49, C55, C56: 100n; C_0603_1608Metric
C29, C36, C43, C50, C57: 4.7n; C_0603_1608Metric
R9, R10, R11, R12, R13, R14, R15, R16, R17, R18: 60; R_0603_1608Metric
U5, U6, U7, U8, U9: MCP251863T-E/9PX; VQFN28_9PX_3p25X3p25EPAD_MCH
Y3, Y4, Y5, Y6, Y7: 40MHz; Crystal_SMD_3225-4Pin_3.2x2.5mm

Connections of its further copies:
+3V3: C28.1, C35.1, C42.1, C49.1, C56.1, U5.14 (VIO), U5.26 (VDD), U6.14 (VIO), U6.26 (VDD), U7.14 (VIO), U7.26 (VDD), U8.14 (VIO), U8.26 (VDD), U9.14 (VIO), U9.26 (VDD); also elsewhere on the board
+5V: C27.1, C34.1, C41.1, C48.1, C55.1, U5.13 (VCC), U6.13 (VCC), U7.13 (VCC), U8.13 (VCC), U9.13 (VCC); also elsewhere on the board
/CAN Output 2/OSC1: C25.1, U5.5 (OSC1), Y3.1
/CAN Output 2/OSC2: C26.1, U5.4 (OSC2), Y3.3
/CAN Output 2/STBY: U5.9 (nINT0/GPIO0/XSTBY), U5.18 (STBY)
/CAN Output 3/OSC1: C32.1, U6.5 (OSC1), Y4.1
/CAN Output 3/OSC2: C33.1, U6.4 (OSC2), Y4.3
/CAN Output 3/STBY: U6.9 (nINT0/GPIO0/XSTBY), U6.18 (STBY)
/CAN Output 4/OSC1: C39.1, U7.5 (OSC1), Y5.1
/CAN Output 4/OSC2: C40.1, U7.4 (OSC2), Y5.3
/CAN Output 4/STBY: U7.9 (nINT0/GPIO0/XSTBY), U7.18 (STBY)
/CAN Output 5/OSC1: C46.1, U8.5 (OSC1), Y6.1
/CAN Output 5/OSC2: C47.1, U8.4 (OSC2), Y6.3
/CAN Output 5/STBY: U8.9 (nINT0/GPIO0/XSTBY), U8.18 (STBY)
/CAN Output 6/OSC1: C53.1, U9.5 (OSC1), Y7.1
/CAN Output 6/OSC2: C54.1, U9.4 (OSC2), Y7.3
/CAN Output 6/STBY: U9.9 (nINT0/GPIO0/XSTBY), U9.18 (STBY)
CAN2 INT: U5.3 (nINT); also elsewhere on the board
CAN2 INT1: U5.8 (nINT1/GPIO1); also elsewhere on the board
CAN2H: R10.1, U5.17 (CANH); also elsewhere on the board
CAN2L: R9.1, U5.16 (CANL); also elsewhere on the board
CAN3 INT: U6.3 (nINT); also elsewhere on the board
CAN3 INT1: U6.8 (nINT1/GPIO1); also elsewhere on the board
CAN3H: R12.1, U6.17 (CANH); also elsewhere on the board
CAN3L: R11.1, U6.16 (CANL); also elsewhere on the board
CAN4 INT: U7.3 (nINT); also elsewhere on the board
CAN4 INT1: U7.8 (nINT1/GPIO1); also elsewhere on the board
CAN4H: R14.1, U7.17 (CANH); also elsewhere on the board
CAN4L: R13.1, U7.16 (CANL); also elsewhere on the board
CAN5 INT: U8.3 (nINT); also elsewhere on the board
CAN5 INT1: U8.8 (nINT1/GPIO1); also elsewhere on the board
CAN5H: R16.1, U8.17 (CANH); also elsewhere on the board
CAN5L: R15.1, U8.16 (CANL); also elsewhere on the board
CAN6 INT: U9.3 (nINT); also elsewhere on the board
CAN6 INT1: U9.8 (nINT1/GPIO1); also elsewhere on the board
CAN6H: R18.1, U9.17 (CANH); also elsewhere on the board
CAN6L: R17.1, U9.16 (CANL); also elsewhere on the board
GND: C25.2, C26.2, C27.2, C28.2, C29.2, C32.2, C33.2, C34.2, C35.2, C36.2, C39.2, C40.2, C41.2, C42.2, C43.2, C46.2, C47.2, C48.2, C49.2, C50.2, C53.2, C54.2, C55.2, C56.2, C57.2, U5.7 (VSS), U5.10 (GND), U5.29 (EP), U6.7 (VSS), U6.10 (GND), U6.29 (EP), U7.7 (VSS), U7.10 (GND), U7.29 (EP), U8.7 (VSS), U8.10 (GND), U8.29 (EP), U9.7 (VSS), U9.10 (GND), U9.29 (EP), Y3.2, Y3.4, Y4.2, Y4.4, Y5.2, Y5.4, Y6.2, Y6.4, Y7.2, Y7.4; also elsewhere on the board
unnamed: C29.1, R9.2, R10.2
unnamed: C36.1, R11.2, R12.2
unnamed: C43.1, R13.2, R14.2
unnamed: C50.1, R15.2, R16.2
unnamed: C57.1, R17.2, R18.2
unnamed: U5.1 (RXCAN), U5.11 (RXD)
unnamed: U5.20 (TXD), U5.28 (TXCAN)
unnamed: U6.1 (RXCAN), U6.11 (RXD)
unnamed: U6.20 (TXD), U6.28 (TXCAN)
unnamed: U7.1 (RXCAN), U7.11 (RXD)
unnamed: U7.20 (TXD), U7.28 (TXCAN)
unnamed: U8.1 (RXCAN), U8.11 (RXD)
unnamed: U8.20 (TXD), U8.28 (TXCAN)
unnamed: U9.1 (RXCAN), U9.11 (RXD)
unnamed: U9.20 (TXD), U9.28 (TXCAN)
SPI0 2CS: U5.25 (nCS); also elsewhere on the board
SPI0 3CS: U6.25 (nCS); also elsewhere on the board
SPI0 4CS: U7.25 (nCS); also elsewhere on the board
SPI0 5CS: U8.25 (nCS); also elsewhere on the board
SPI0 6CS: U9.25 (nCS); also elsewhere on the board
SPI0 RX: U5.24 (SDO), U6.24 (SDO), U7.24 (SDO), U8.24 (SDO), U9.24 (SDO); also elsewhere on the board
SPI0 SCK: U5.22 (SCK), U6.22 (SCK), U7.22 (SCK), U8.22 (SCK), U9.22 (SCK); also elsewhere on the board
SPI0 TX: U5.23 (SDI), U6.23 (SDI), U7.23 (SDI), U8.23 (SDI), U9.23 (SDI); also elsewhere on the board

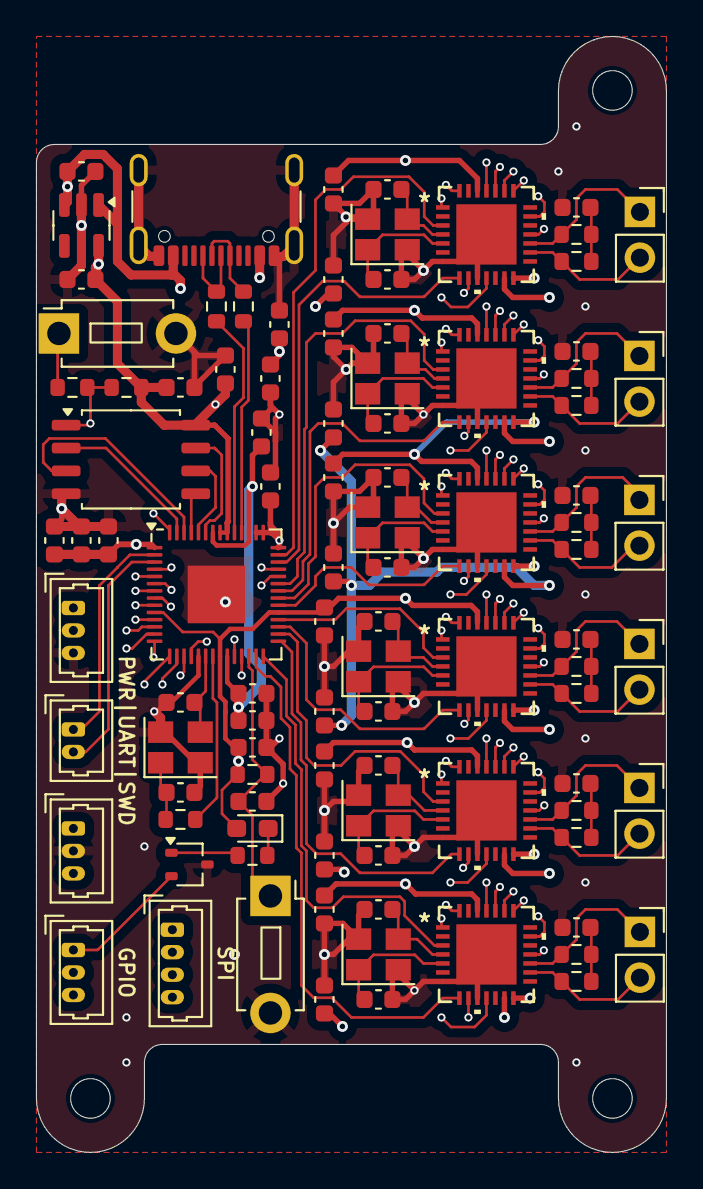
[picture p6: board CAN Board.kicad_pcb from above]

Board: 4 copper layers, 35.0 x 62.0 mm, 98 parts (0 on the bottom side), 101 nets.

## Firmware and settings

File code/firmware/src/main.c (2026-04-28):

#include "pico/stdlib.h"
#include "malloc.h"

#include "tusb.h" // Required for tud_cdc_connected()
#include "hardware/spi.h"

#include "canapi.h"

#include "pins.h"
#include "logging.h"
#include "can.h"

///////////////////////////////////////
// User params
///////////////////////////////////////

#define EXT_SPI_BAUD 1000000
#define CAN_BITRATE CAN_BITRATE_1M_50

// get protocol data over stdio else it will use SPI
#define PKT_OVER_STDIO

#ifdef PKT_OVER_STDIO
#define read_bytes(buff, len) fread(buff, len, 1, stdin)
#define write_bytes(buff, len)    \
    fwrite(buff, len, 1, stdout); \
    fflush(stdout)
#else
#define read_bytes(buff, len) spi_read_blocking(EXT_SPI, 0, buff, len)
#define write_bytes(buff, len) spi_write_blocking(EXT_SPI, buff, len)
#endif

#define wrap_led_on(statements) \
    gpio_put(EXT_GPIO_15, 0);   \
    statements                  \
        gpio_put(EXT_GPIO_15, 1);

/**
 * Initializes the external spi
 */
void init_ext_spi()
{
    debug("EXT SPI setup: Starting setup...\n");

    uint baud = spi_init(EXT_SPI, EXT_SPI_BAUD);
    spi_set_slave(EXT_SPI, true);

    gpio_set_function(EXT_SPI_SCK, GPIO_FUNC_SPI);
    gpio_set_function(EXT_SPI_TX, GPIO_FUNC_SPI);
    gpio_set_function(EXT_SPI_RX, GPIO_FUNC_SPI);
    gpio_set_function(EXT_SPI_CS, GPIO_FUNC_SPI);

    debug("EXT SPI setup: Done setting up at baud %u!\n", baud);
}

typedef enum : uint8_t
{
    SEND_FRAME,
    RECV_RX_EVENTS,
    RECV_TX_EVENTS,
    RECV_CAN_INFO
} host_command_t;

typedef enum : uint8_t
{
    CMD_RESPONSE_OK,
    CMD_RESPONSE_BAD_PKT,
    CMD_RESPONSE_CMD_UNKNOWN,
    CMD_RESPONSE_CMD_MALFORMED,
    CMD_RESPONSE_TIMEOUT,
    CMD_RESPONSE_FAILED,
    CMD_RESPONSE_NO_RESOURCES
} command_resp_t;

typedef enum : uint8_t
{
    FRAME_OPTION_EXTENDED = (1 << 0), // Use CAN extended 29 bit arbitration
    FRAME_OPTION_REMOTE = (1 << 1),   // This is a CAN remote frame
    FRAME_OPTION_USE_FIFO = (1 << 2), // Use TX FIFO instead of directly going into TX priority queue
    FRAME_OPTION_USE_UREF = (1 << 3), // Add a user reference to the frame (else it will default to 0)
} frame_options_t;

typedef struct
{
    uint8_t controller;
    frame_options_t options;
    uint8_t dlc;
} send_frame_cmd_data_t;

void send_response_pkt(command_resp_t resp_code, void *data, uint16_t data_size)
{
    uint8_t tmp = 0xAA;
    write_bytes(&tmp, 1);
    write_bytes(&resp_code, sizeof(resp_code));
    write_bytes(&data_size, 2);
    if (data_size)
        write_bytes(data, data_size);
    tmp = 0x55;
    write_bytes(&tmp, 1);
}

void handle_send_frame_cmd(uint8_t *data, uint16_t data_size)
{
    // Extract frame header data
    if (data_size < sizeof(send_frame_cmd_data_t))
    {
        error("Send frame: Not enough data supplied to extract header (expected %hhd, got %hhd)\n", sizeof(send_frame_cmd_data_t), data_size);
        send_response_pkt(CMD_RESPONSE_CMD_MALFORMED, NULL, 0);
        return;
    }
    send_frame_cmd_data_t *frame_cmd_data = (send_frame_cmd_data_t *)data;

    bool extended = (frame_cmd_data->options & FRAME_OPTION_EXTENDED);
    bool remote = (frame_cmd_data->options & FRAME_OPTION_REMOTE);
    bool use_fifo = (frame_cmd_data->options & FRAME_OPTION_USE_FIFO);
    bool use_uref = (frame_cmd_data->options & FRAME_OPTION_USE_UREF);

    debug("Send frame: Received header (controller=%hhd, extended=%hhd, remote=%hhd, fifo=%hhd, uref=%hhd, dlc=%hhd)\n",
          frame_cmd_data->controller,
          extended,
          remote,
          use_fifo,
          use_uref,
          frame_cmd_data->dlc);

    if (frame_cmd_data->controller >= NUM_CAN_CONTROLLERS)
    {
        error("Send frame: Invalid controller number (controller=%hhd, must be between 0 and %d)\n", frame_cmd_data->controller, NUM_CAN_CONTROLLERS - 1);
        send_response_pkt(CMD_RESPONSE_CMD_MALFORMED, NULL, 0);
        return;
    }

    if (frame_cmd_data->dlc > 8)
    {
        error("Send frame: Invalid DLC (dlc=%hhd > 8)\n", frame_cmd_data->dlc);
        send_response_pkt(CMD_RESPONSE_CMD_MALFORMED, NULL, 0);
        return;
    }

    // Calculate and verify sizes are correct
    uint8_t arbitration_idx = sizeof(send_frame_cmd_data_t);
    uint8_t uref_idx = arbitration_idx + (extended ? 4 : 2); // 16 bits for normal arbitration (11 bits) and 32 bits for extended (29 bits)
    uint8_t data_idx = uref_idx + (use_uref ? 4 : 0);        // 32 bits for user reference if included
    uint8_t expected_size = data_idx + (remote ? 0 : frame_cmd_data->dlc);                                         // Total expected size is the header + arbitration + optional user reference + data
    if (data_size != expected_size)
    {
        error("Send frame: Invalid amount of data supplied for CAN frame (expected %hhd bytes, got %hhd bytes)\n", expected_size, data_size);
        send_response_pkt(CMD_RESPONSE_CMD_MALFORMED, NULL, 0);
        return;
    }

    // Get arbitration ID
    uint32_t arbitration = 0;
    // We use memcpy here as it may not be word aligned
    memcpy(&arbitration, data + arbitration_idx, (extended ? 4 : 2));
    debug("Send frame: Arbitration ID: %08x\n", arbitration);

    // Make frame
    can_frame_t frame;
    can_make_frame(&frame, extended, arbitration, frame_cmd_data->dlc, data + data_idx, remote);

    // Set user reference if included
    if (use_uref)
    {
        uint32_t uref;
        memcpy(&uref, data + uref_idx, 4);
        debug("Send frame: User reference: %08x\n", uref);
        can_frame_set_uref(&frame, (void *)uref);
    }

    // Send frame
    can_errorcode_t rc = send_can_frame(frame_cmd_data->controller, &frame, use_fifo);
    if (rc == CAN_ERC_NO_ERROR)
    {
        send_response_pkt(CMD_RESPONSE_OK, NULL, 0);
        return;
    }

    send_response_pkt(CMD_RESPONSE_FAILED, &rc, sizeof(rc));
}

void handle_recv_rx_events_cmd(uint8_t *data, uint16_t data_size)
{
    if (data_size != 1)
    {
        error("Receive RX events: Invalid data size (expected 1 byte, got %hhd bytes)\n", data_size);
        send_response_pkt(CMD_RESPONSE_CMD_MALFORMED, NULL, 0);
        return;
    }

    // Get controller bitmap
    uint8_t controller = data[0];
    debug("Receive RX events: Received controller: %hhd\n", controller);

    if (controller >= NUM_CAN_CONTROLLERS)
    {
        error("Receive RX events: Invalid controller number (controller=%hhd, must be between 0 and %d)\n", controller, NUM_CAN_CONTROLLERS - 1);
        send_response_pkt(CMD_RESPONSE_CMD_MALFORMED, NULL, 0);
        return;
    }

    uint8_t *buff;
    int buff_size = get_can_rx_events(controller, &buff);
    if (buff_size < 0)
    {
        send_response_pkt(CMD_RESPONSE_FAILED, NULL, 0);
        return;
    }

    // Send the buffer back to the host
    send_response_pkt(CMD_RESPONSE_OK, buff, buff_size);
    free(buff);
}

void handle_recv_tx_events_cmd(uint8_t *data, uint16_t data_size)
{
    if (data_size != 1)
    {
        error("Receive TX events: Invalid data size (expected 1 byte, got %hhd bytes)\n", data_size);
        send_response_pkt(CMD_RESPONSE_CMD_MALFORMED, NULL, 0);
        return;
    }

    // Get controller
    uint8_t controller = data[0];

    debug("Receive TX events: Received controller: %hhd\n", controller);

    if (controller >= NUM_CAN_CONTROLLERS)
    {
        error("Receive TX events: Invalid controller number (controller=%hhd, must be between 0 and %d)\n", controller, NUM_CAN_CONTROLLERS - 1);
        send_response_pkt(CMD_RESPONSE_CMD_MALFORMED, NULL, 0);
        return;
    }

    uint8_t *buff;
    int buff_size = get_can_tx_events(controller, &buff);
    if (buff_size < 0)
    {
        send_response_pkt(CMD_RESPONSE_FAILED, NULL, 0);
        return;
    }

    // Send the buffer back to the host
    send_response_pkt(CMD_RESPONSE_OK, buff, buff_size);
    free(buff);
}

void loop()
{

    uint8_t start;
    read_bytes(&start, 1);
    if (start != 0xAA)
    {
        error("Received invalid start byte: %02hhx\n", start);
        return;
    }

    host_command_t cmd;
    read_bytes(&cmd, sizeof(cmd));

    uint16_t data_size;
    read_bytes(&data_size, 2);

    uint8_t *data = malloc(data_size);
    if (data == NULL)
    {
        error("Failed to allocate memory for command data\n");
        send_response_pkt(CMD_RESPONSE_NO_RESOURCES, NULL, 0);
        // We still need to read the data and end byte from the host to keep the protocol in sync, but we can just discard it since we don't have resources to handle the command
        uint8_t tmp[32];
        while (data_size > 0)
        {
            uint16_t to_read = data_size > sizeof(tmp) ? sizeof(tmp) : data_size;
            read_bytes(tmp, to_read);
            data_size -= to_read;
        }
        // Read and discard end byte
        read_bytes(tmp, 1);

        return;
    }

    read_bytes(data, data_size);

    uint8_t end;
    read_bytes(&end, 1);
    if (end != 0x55)
    {
        error("Received invalid end byte: %02hhx\n", end);
        send_response_pkt(CMD_RESPONSE_BAD_PKT, NULL, 0);
        free(data);
        return;
    }

    // Handle commands
    // TODO make these command work with more than just one controller
    switch (cmd)
    {
    case SEND_FRAME:
        wrap_led_on(handle_send_frame_cmd(data, data_size);) break;
    case RECV_RX_EVENTS:
        wrap_led_on(handle_recv_rx_events_cmd(data, data_size);) break;
    case RECV_TX_EVENTS:
        wrap_led_on(handle_recv_tx_events_cmd(data, data_size);) break;
    default:
        error("Received unknown command: %hhd\n", cmd);
        send_response_pkt(CMD_RESPONSE_CMD_UNKNOWN, NULL, 0);
        break;
    }

    free(data);
}

void speed_test(int controller_num, uint32_t test_duration_ms)
{
    info("Starting speed test on controller %d...\n", controller_num);

    // Speed test
    uint32_t num_frames_sent = 0;

    can_frame_t frame;
    can_make_frame(&frame, true, 0xdeadbeef, 8, (uint8_t[]){0xde, 0xad, 0xbe, 0xef, 0xde, 0xad, 0xbe, 0xef}, false);

    uint32_t start_time = time_us_32();
    while (time_us_32() - start_time < test_duration_ms * 1000) // test_duration_ms seconds
    {
        can_errorcode_t rc = send_can_frame(controller_num, &frame, false);
        if (rc == CAN_ERC_NO_ERROR)
            num_frames_sent++;
    }  

    info("Speed test completed. Sent %lu frames in %lu ms.\n", num_frames_sent, test_duration_ms);
    // Read out all target_specific flags in can controller to see if there were any errors
    info("Target-specific flags for controller %d:\n", controller_num);
    info("  seq_bad: %lu\n", can_controllers[controller_num].target_specific.seq_bad);
    info("  txqsta_bad: %lu\n", can_controllers[controller_num].target_specific.txqsta_bad);
    info("  txqua_bad: %lu\n", can_controllers[controller_num].target_specific.txqua_bad);
    info("  bus_off: %lu\n", can_controllers[controller_num].target_specific.bus_off);
    info("  spurious: %lu\n", can_controllers[controller_num].target_specific.spurious);
    info("  crc_bad: %lu\n", can_controllers[controller_num].target_specific.crc_bad);
}

int main()
{
    stdio_init_all();
    stdio_set_translate_crlf(&stdio_usb, false);

    // Wait for the USB CDC connection
    while (!tud_cdc_connected())
    {
        // Optional: Add a small delay or perform other non-blocking tasks
        sleep_ms(100);
    }

    // Turn off led for start
    gpio_init(EXT_GPIO_15);
    gpio_set_dir(EXT_GPIO_15, 1);
    gpio_put(EXT_GPIO_15, 1);

    info("Starting setup...\n");

    init_ext_spi();
    can_bitrate_t bitrate = {.profile = CAN_BITRATE};
    setup_can_controllers(&bitrate);

    info("CAN board ready!\n");

    // for (int i = 0; i < NUM_CAN_CONTROLLERS; i++)
    // {
    //     speed_test(i, 1000);
    //     speed_test(NUM_CAN_CONTROLLERS - 1 - i, 1000);
    // }
    

    while (1)
        loop();

}

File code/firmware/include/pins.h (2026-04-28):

#ifndef PINS_H
#define PINS_H

#include "pico/stdlib.h"

// CAN controllers
#define CAN_SPI spi0
#define CAN_SPI_SCK 2
#define CAN_SPI_TX 3
#define CAN_SPI_RX 4

static uint8_t can_spi_cs_pins[6] = {5,6,7,8,9,10};
static uint8_t can_int_pins[6] = {29,25,23,21,19,17};
static uint8_t can_rx_int_pins[6] = {28,24,22,20,18,16};

// External UART
#define EXT_UART uart0
#define EXT_UART_TX 0
#define EXT_UART_RX 1

// External SPI
#define EXT_SPI spi1
#define EXT_SPI_TX 11
#define EXT_SPI_RX 12
#define EXT_SPI_CS 13
#define EXT_SPI_SCK 14

// External GPIO
#define EXT_GPIO_15 15
#define EXT_GPIO_26 26
#define EXT_GPIO_27 27

#endif // PINS_H

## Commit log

2024-11-20 added board
    [CAN Board.kicad_pcb, CAN Board.kicad_sch, CAN_Output.kicad_sch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]
2024-11-21 moving stuff
    [CAN Board.kicad_pcb, CAN Board.kicad_sch]
2024-11-21 moving components
    [CAN Board.kicad_pcb]
2024-11-24 routed data, power lift
    [CAN Board.kicad_pcb]
2024-12-05 it has no errors :)
    [CAN Board-B_Cu.gbr, CAN Board-B_Mask.gbr, CAN Board-B_Paste.gbr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]
2024-12-08 cleaning up and minor updates
    [CAN Board-B_Cu.gbr, CAN Board-B_Mask.gbr, CAN Board-B_Paste.gbr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]
2024-12-08 slight moving of parts
    [CAN Board.kicad_pcb]
2024-12-08 added mounting holes
    [CAN Board.kicad_pcb, CAN Board.kicad_sch]
2025-01-26 updated baord
    [BOM.csv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]
2025-01-26 added LED and cleanup
    [BOM.csv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]
2025-01-26 updated readne
    [CAN Board.kicad_pcb]
2025-01-27 added basic framework
2025-01-27 slight fix to header
    [CAN Board-B_Cu.gbr, CAN Board-B_Mask.gbr, CAN Board-B_Paste.gbr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]
2025-02-02 updated board
    [BOM-with-part-numbers.csv, BOM.csv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]
2025-02-02 added screw holes
    [CAN Board-B_Cu.gbr, CAN Board-B_Mask.gbr, CAN Board-B_Paste.gbr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]
2025-02-02 added part numbers
    [BOM-with-part-numbers.csv]
2025-02-13 added kicad zip
2025-02-14 updated silkscreen
    [CAN Board.kicad_pcb]
2025-02-15 updated stby pinout
    [CAN Board.kicad_pcb, CAN_Output.kicad_sch]
2025-02-15 finished pin config
2025-02-16 added simple code
    [CAN Board.kicad_pcb]
2025-02-21 updated CAN termination
    [BOM.csv, CAN Board.kicad_pcb, CAN Board.kicad_sch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]
2025-02-21 updated BOM
    [BOM-with-part-numbers.csv]
2025-03-17 updated code
    [BOM.csv, CAN Board BOM.ods, CAN Board.kicad_pcb]
2025-04-06 worked on some stuff
    [CAN Board.kicad_sch, CAN_Output.kicad_sch]
2025-05-04 updated to be pico project
2026-02-19 random update (IDK)
    [CAN Board.kicad_pcb, CAN Board.kicad_sch, CAN_Output.kicad_sch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]
2026-02-23 fully functioning CAN board!
